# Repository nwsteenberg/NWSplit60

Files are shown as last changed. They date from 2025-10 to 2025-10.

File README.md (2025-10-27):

# NWSplit60 Keyboard
NWSplit80 is a split, column staggered, ergonomic keyboard designed for ISO layout. 

------------------------------------------------

NWSplit60

------------------------------------------------

## Features: 
* Column Staggered
* Asymetric to support ISO layout
* Thumb cluster and inner stretch keys on both sides
* RP2040-zero controller
* Hotswap MX switches

## Firmware:
- QMK: `#INSERT LINK`
- VIAL:  `#INSERT LINK`

## TODO:
- [ ] Images
- [ ] QMK PR
- [ ] VIAL PR
- [ ] File Structure
- [ ] Build Guide
- [ ] Detailed BOM

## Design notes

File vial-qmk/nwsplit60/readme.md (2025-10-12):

# nwsplit60

nwsplit60

*A short description of the keyboard/project*

* Keyboard Maintainer: [Nikolaj W. Steenberg](https://github.com/nwsteenberg)
* Hardware Supported: RP2040 @TODO

Make example for this keyboard (after setting up your build environment):

    make nwsplit60:default

Flashing example for this keyboard:

    make nwsplit60:default:flash

See the [build environment setup](https://docs.qmk.fm/#/getting_started_build_tools) and the [make instructions](https://docs.qmk.fm/#/getting_started_make_guide) for more information. Brand new to QMK? Start with our [Complete Newbs Guide](https://docs.qmk.fm/#/newbs).

## Bootloader

Enter the bootloader in 3 ways:

* **Bootmagic reset**: Hold down the key at (0,0) in the matrix (usually the top left key or Escape) and plug in the keyboard
* **Physical reset button**: Briefly press the button on the back of the PCB - some may have pads you must short instead
* **Keycode in layout**: Press the key mapped to `QK_BOOT` if it is available

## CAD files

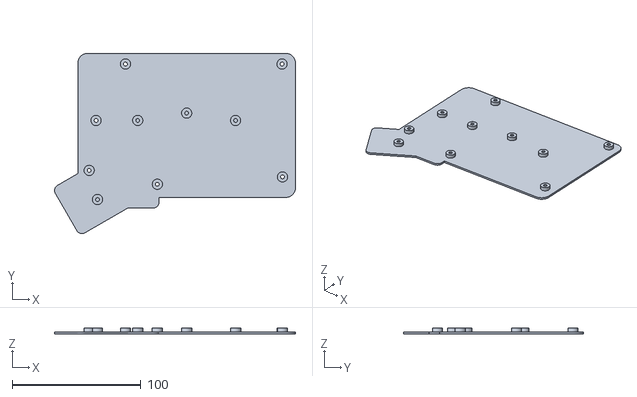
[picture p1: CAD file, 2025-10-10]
cases/right_base.stl
187.1 x 140.0 x 4.50

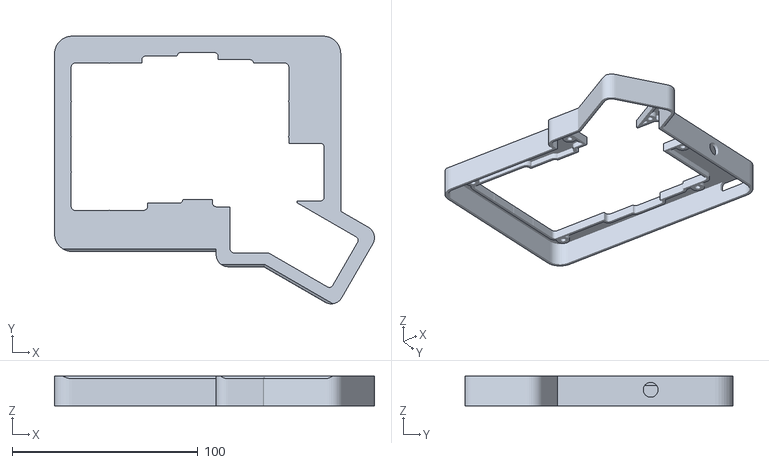
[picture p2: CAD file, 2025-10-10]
cases/left_shell.stl
172.1 x 144.0 x 16.1

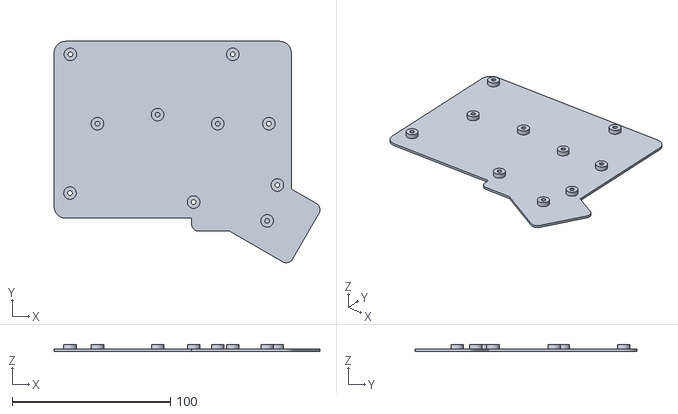
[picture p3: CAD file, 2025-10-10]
cases/left_base.stl
168.1 x 140.0 x 4.50

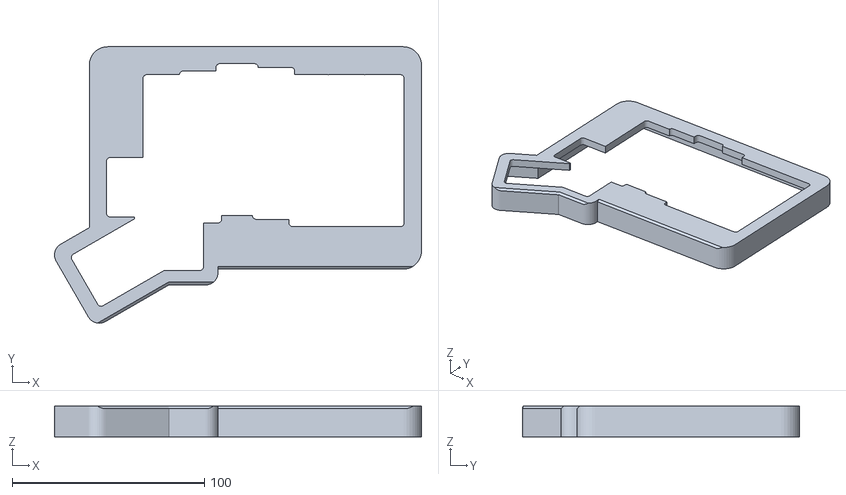
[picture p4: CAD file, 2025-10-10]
cases/right_shell.stl
191.1 x 144.0 x 16.1

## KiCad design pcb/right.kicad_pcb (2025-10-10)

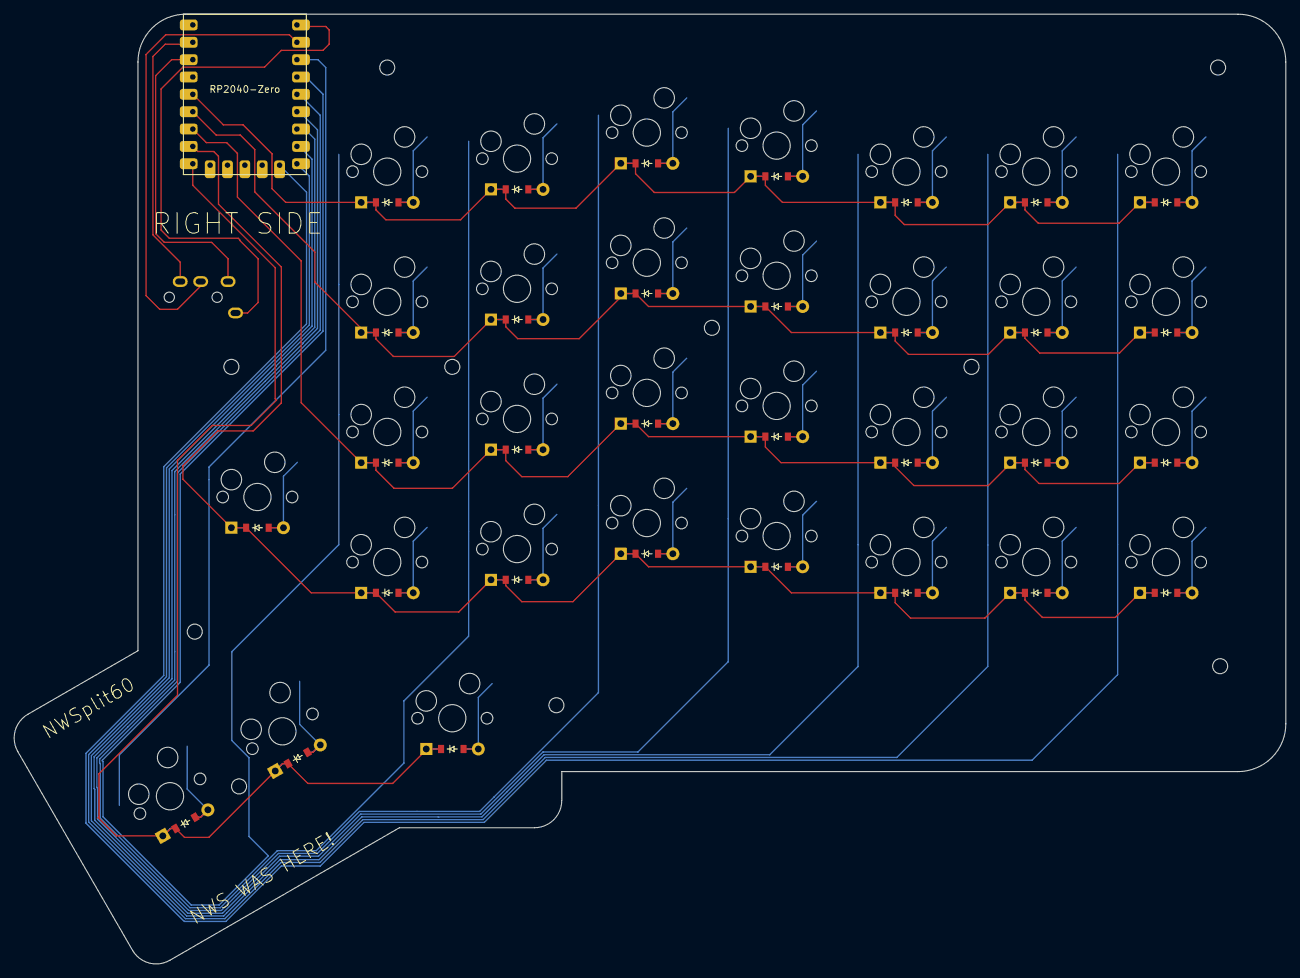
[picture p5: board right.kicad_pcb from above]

Board: 2 copper layers, 186.1 x 139.0 mm, 75 parts (0 on the bottom side), 45 nets.

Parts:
D1, D2, D3, D4, D5, D6, D7, D8, D9, D10, D11, D12, D13, D14, D15, D16, D17, D18, D19, D20, D21, D22, D23, D24, D25, D26, D27, D28, D29, D30, D31, D32: ComboDiode
MH1, MH2, MH3, MH4, MH5, MH6, MH7, MH8, MH9, MH10: mounting_hole_npth
S1, S2, S3, S4, S5, S6, S7, S8, S9, S10, S11, S12, S13, S14, S15, S16, S17, S18, S19, S20, S21, S22, S23, S24, S25, S26, S27, S28, S29, S30, S31, S32: MX
TRRS1: trrs_pj320a

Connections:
GP2: S29.1, S32.1
GP3: S25.1, S26.1, S27.1, S28.1, S31.1
GP4: S21.1, S22.1, S23.1, S24.1, S30.1
GP5: S17.1, S18.1, S19.1, S20.1
GP6: S13.1, S14.1, S15.1, S16.1
GP7: S9.1, S10.1, S11.1, S12.1
GP8: S5.1, S6.1, S7.1, S8.1
GP9: S1.1, S2.1, S3.1, S4.1
GP14: D30.1, D31.1, D32.1
GP15: D1.1, D5.1, D9.1, D13.1, D17.1, D21.1, D25.1, D29.1
GP26: D2.1, D6.1, D10.1, D14.1, D18.1, D22.1, D26.1
GP27: D3.1, D7.1, D11.1, D15.1, D19.1, D23.1, D27.1
GP28: D4.1, D8.1, D12.1, D16.1, D20.1, D24.1, D28.1
mirror_center_only: D31.2, S31.2
mirror_index_bottom: D21.2, S21.2
mirror_index_home: D22.2, S22.2
mirror_index_num: D24.2, S24.2
mirror_index_top: D23.2, S23.2
mirror_inner_bottom: D25.2, S25.2
mirror_inner_home: D26.2, S26.2
mirror_inner_num: D28.2, S28.2
mirror_inner_top: D27.2, S27.2
mirror_middle_bottom: D17.2, S17.2
mirror_middle_home: D18.2, S18.2
mirror_middle_num: D20.2, S20.2
mirror_middle_top: D19.2, S19.2
mirror_outer_bottom: D5.2, S5.2
mirror_outer_home: D6.2, S6.2
mirror_outer_num: D8.2, S8.2
mirror_outer_top: D7.2, S7.2
mirror_pinky_bottom: D9.2, S9.2
mirror_pinky_home: D10.2, S10.2
mirror_pinky_num: D12.2, S12.2
mirror_pinky_top: D11.2, S11.2
mirror_reach_only: D32.2, S32.2
mirror_reachy_bottom: D1.2, S1.2
mirror_reachy_home: D2.2, S2.2
mirror_reachy_num: D4.2, S4.2
mirror_reachy_top: D3.2, S3.2
mirror_ring_bottom: D13.2, S13.2
mirror_ring_home: D14.2, S14.2
mirror_ring_num: D16.2, S16.2
mirror_ring_top: D15.2, S15.2
mirror_stretch_bottom: D29.2, S29.2
mirror_tuck_only: D30.2, S30.2

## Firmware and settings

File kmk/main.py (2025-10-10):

# main.py
from kmk.modules.holdtap import HoldTap
from kmk.modules.layers import Layers
from kmk.modules.split import Split, SplitType
from kmk.scanners import DiodeOrientation
from kmk.keys import KC
from kmk.kmk_keyboard import KMKKeyboard
from kmk.extensions.international import International
import board

keyboard = KMKKeyboard()
keyboard.extensions.append(International())

# Homerow mods
holdtap = HoldTap()
holdtap.tap_time = 100  # Tab timeout in ms
keyboard.modules.append(holdtap)
keyboard.modules.append(Layers())

split = Split(
    split_flip=True,  # If both halves are the same, but flipped, set this True
    split_type=SplitType.UART,
    split_target_left=True,  # Left is main
    data_pin=board.GP0,
    data_pin2=board.GP1,
    use_pio=True,
    uart_flip=True)  # Both boards have TX/RX on same pins (GP0/GP1)
keyboard.modules.append(split)

# Left to right (right split - flipped on left)
keyboard.col_pins = (board.GP9, board.GP8, board.GP7, board.GP6, board.GP5, board.GP4, board.GP3, board.GP2)
# Top to bot
keyboard.row_pins = (board.GP28,
                     board.GP27,
                     board.GP26,
                     board.GP15,
                     board.GP14)
keyboard.diode_orientation = DiodeOrientation.COL2ROW

# HoldTab mods
HT_1 = KC.HT(KC.ESCAPE, KC.CTRL)

# fmt:off
keyboard.coord_mapping = [
      1,  2,  3,  4,  5,  6,            46, 45, 44, 43, 42, 41, 40,
      9, 10, 11, 12, 13, 14,            54, 53, 52, 51, 50, 49, 48,
     17, 18, 19, 20, 21, 22,            62, 61, 60, 59, 58, 57, 56,
     25, 26, 27, 28, 29, 30, 31,    71, 70, 69, 68, 67, 66, 65, 64,
                     37, 38, 39,    79, 78, 77
]
# fmt:on
keyboard.keymap = [
    # Base Layer
    [
        KC.ESC,     KC.N1,     KC.N2,     KC.N3,     KC.N4,     KC.N5,                             KC.N6,     KC.N7,     KC.N8,     KC.N9,     KC.N0,     KC.MINS,     KC.EQL,
        KC.TAB,     KC.Q,      KC.W,      KC.E,      KC.R,      KC.T,                              KC.Y,      KC.U,      KC.I,      KC.O,      KC.P,      KC.LBRC,     KC.RBRC,
        HT_1,       KC.A,      KC.S,      KC.D,      KC.F,      KC.G,                              KC.H,      KC.J,      KC.K,      KC.L,      KC.SCLN,   KC.QUOT,     KC.NUHS,
        KC.LSFT,    KC.Z,      KC.X,      KC.C,      KC.V,      KC.B,       KC.END,    KC.HOME,    KC.N,      KC.M,      KC.COMM,   KC.DOT,    KC.SLSH,   KC.RGUI,     KC.RSFT,
                                                     KC.LALT,   KC.SPC,     KC.MO(1),  KC.ENT,     KC.BSPC,   KC.RALT
    ],
    # M1 Layer
    [
        KC.NO,     KC.F1,     KC.F2,     KC.F3,     KC.F4,     KC.F5,                             KC.F6,     KC.F7,     KC.F8,     KC.F9,     KC.F10,    KC.F11,    KC.F12,
        KC.NO,     KC.N1,     KC.N2,     KC.N3,     KC.N4,     KC.N5,                             KC.N6,     KC.N7,     KC.N8,     KC.N9,     KC.N0,     KC.NO,     KC.NO,
        KC.NO,     KC.NO,     KC.NO,     KC.NO,     KC.NO,     KC.NO,                             KC.LEFT,   KC.DOWN,   KC.UP,     KC.RIGHT,  KC.NO,     KC.NO,     KC.NO,
        KC.NO,     KC.NUBS,   KC.NO,     KC.NO,     KC.NO,     KC.NO,     KC.NO,     KC.NO,       KC.NO,     KC.NO,     KC.NO,     KC.NO,     KC.NO,     KC.NO,     KC.NO,
                                                    KC.NO,     KC.NO,     KC.NO,     KC.NO,       KC.DEL,    KC.NO
    ]

]

if __name__ == '__main__':
    keyboard.go()

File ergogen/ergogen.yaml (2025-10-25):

units:
  padding: 5

  shellThickness: 2
  plateHeight: 1.6 # MX Key plate height (Ideal. Probably 1.6 if using PCB plate)
  topOfPlateToTopOfPCBSwitchHeight: 5 - plateHeight # 5mm between top of plate and top of Keyboard PCB
  pcbHeight: 1.6 # Keyboard PCB
  componentHeight: 3 # total with connectors and everything (closer to 5 but we want some more room)
  baseHeight: 1.5 # 3d Printed case bottom height

  topOfShellToTopOfPlate: 5
  wallHeight: topOfShellToTopOfPlate + plateHeight + topOfPlateToTopOfPCBSwitchHeight + pcbHeight + componentHeight + baseHeight
  standoffHeightBase: componentHeight + baseHeight # Standoffs should account for MCU height
  standoffHeightShell: topOfShellToTopOfPlate 

  wallExpander: 4 # buffer between wall and pcb/plate
  tolerance: 0.5

  standoffSize: 4 # Radius of standoff (outer)
  screwSize: 1.5 # Radius of insert
points:
  zones:
    matrix:
      anchor:
        shift: [40, -200] # Move into KiCAD position
        rotate: 0
      columns:
        reachy.key.mirror.skip: false
        #reachy.rows.bottom.mirror.skip: true
        reachy.key.skip: true
        reachy.key.column_net: "GP9"
        
        #outer.rows.num.mirror.skip: false
        #outer.rows.num.skip: true
        outer.key.column_net: "GP8"
        
        pinky.key.column_net: "GP7"
        
        ring.key.stagger: 0.2U
        ring.key.column_net: "GP6"
        
        middle.key.stagger: 0.1U
        middle.key.column_net: "GP5"
        middle.rows.home.bind: [2.2U,3.2U,2.2U,3.2U]
        middle.rows.home.mirror.bind: [2.2U,3.2U,2.2U,4.2U]

        index.key.stagger: -0.2U
        index.key.column_net: "GP4"
        
        inner.key.stagger: -0.1U
        inner.key.column_net: "GP3"
        
        stretch.rows.num.skip: true
        stretch.rows.top.skip: true
        stretch.rows.home.skip: true
        stretch.rows.home.adjust.shift: [0,0.75U]
        stretch.rows.home.height: 1.5U
        stretch.rows.bottom.skip: false
        #stretch.rows.bottom.adjust.shift: [0,0.25U]
        stretch.rows.bottom.adjust.shift: [0,0.5U]
        stretch.rows.bottom.height: 1.5U
        stretch.key.column_net: "GP2"
      rows:
        bottom.padding: U
        bottom.row_net: "GP15"
        home.padding: U
        home.row_net: "GP26"
        top.padding: U
        top.row_net: "GP27"
        num.padding: U
        num.row_net: "GP28"
    thumb:
      anchor:
        ref: matrix_inner_bottom
        shift: [-0.5U, -1.2U]
      columns:
        tuck:
          key.name: matrix_thumb_tuck
          key.column_net: "GP4"
          key.bind: [1U,1U,0U,0U]
        center:
          key.name: matrix_thumb_center
          key.splay: -30
          key.origin: [-0.5U, -0.5U]
          key.height: 1.5U
          key.adjust.shift: [0, 0.25U]
          key.column_net: "GP3"
          key.bind: [0.25U+(padding/2),padding/2,0.25U+(padding/2),1U]
        reach:
          key.name: matrix_thumb_reach
          key.origin: [-0.5U, -0.5U]
          key.column_net: "GP2"
          key.height: 1.5U
          key.adjust.shift: [0, 0.25U]
          key.bind: [0.25U+(padding/2),padding/2,0.25U+(padding/2),0U]
      rows:
        only:
          row_net: "GP14"

  mirror:
    ref: matrix_pinky_home
    distance: 270

outlines:
  _outline: # Starting outline of Keyboard
    - what: rectangle
      where: /.atrix_middle_home/
      bound: true
      fillet: 3
      size: U
    - what: rectangle
      where: /.atrix_thumb/
      bound: true
      size: U
    - what: rectangle
      where: true
      size: U+padding
  outline:  # With a wallExpander
    - what: outline
      name: _outline
      expand: wallExpander
  _mcu_hole:
    - what: rectangle
      where: /.atrix_middle_home/
      size: [21, 28]
      adjust.shift: [59, 44.5]
  _trrs_rep:
    - what: rectangle
      where: /.atrix_middle_home/
      size: [16+1, 6+1]
      adjust:
        shift: [67.5,14] 
  _mx_cutout:
    - what: rectangle
      size: 14
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

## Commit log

2025-10-10 Added ergogen footprint
2025-10-22 Updated ergogen with new bottom plate. Fixed up errors in keymap
    [ergogen.yaml]
